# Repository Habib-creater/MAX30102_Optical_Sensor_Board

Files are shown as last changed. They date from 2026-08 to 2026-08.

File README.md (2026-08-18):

# MAX30102 Optical Sensor Board

<p align="center">
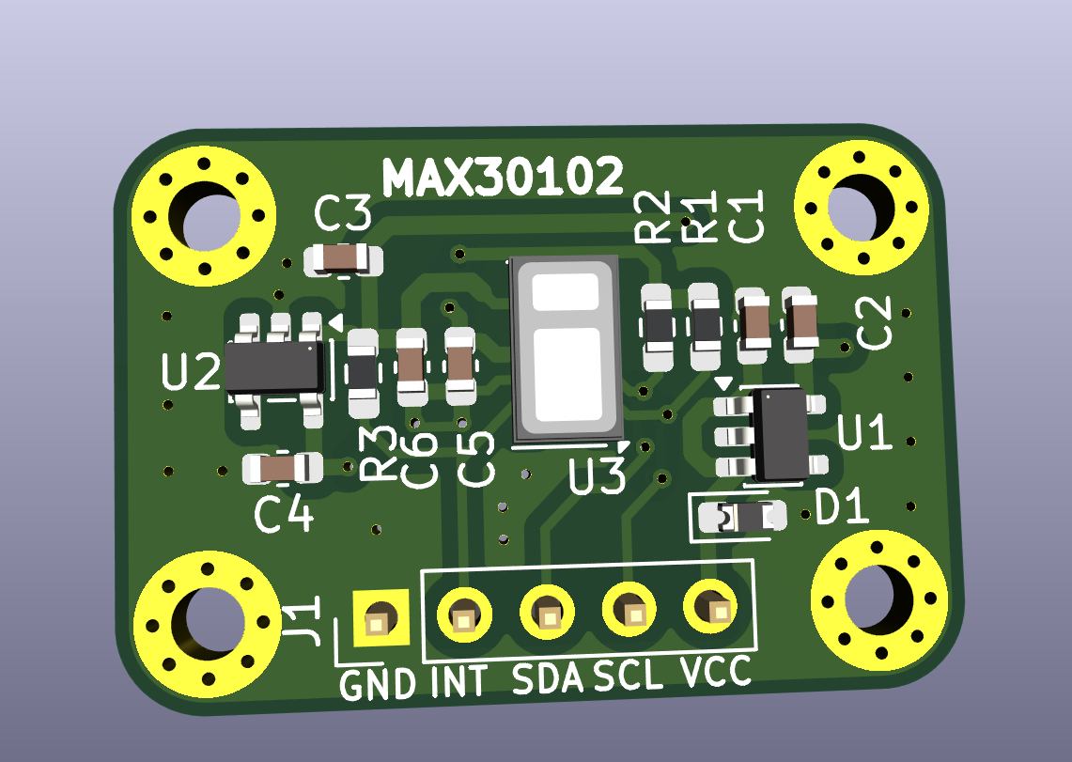
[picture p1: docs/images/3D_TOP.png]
MAX30102 Optical Sensor Board
  
</p>

<p align="center">
  <strong>MAX30102 • Dual Supply Rails • I²C • 2-Layer PCB • KiCad</strong>
</p>

<p align="center">
  A compact optical sensing board centered on the MAX30102
  integrated pulse-oximetry and heart-rate sensor.
</p>

<p align="center">
  <a href="docs/max30102_schematic.pdf">Schematic</a> •
  <a href="bom/MAX30102_BOM.csv">BOM</a> •
  <a href="manufacturing/gerbers/">Gerbers</a> •
  <a href="hardware/kicad/">KiCad Files</a>
</p>

---

## Overview

The **MAX30102 Optical Sensor Board** is a compact 2-layer PCB designed
around the **MAX30102** sensor.

The board provides the MAX30102 with dedicated supply regulation,
I²C connectivity, interrupt access, and a 5-pin external interface.

The complete hardware design package is included in this repository,
covering the native **KiCad project**, schematic, PCB layout, BOM,
Gerber and drill manufacturing files, pick-and-place data, and board
documentation.

---

## Quick Access

| Resource | Description |
|---|---|
| 📐 [Schematic PDF](docs/max30102_schematic.pdf) | Electrical schematic |
| 📦 [Bill of Materials](bom/MAX30102_BOM.csv) | Component BOM |
| 🏭 [Gerber & Drill Files](manufacturing/gerbers/) | PCB manufacturing data |
| 🔧 [KiCad Project](hardware/kicad/) | Native KiCad design files |
| 🖼️ [Board Images](docs/images/) | 3D renders and PCB views |
| 📍 [Pick-and-Place Data](manufacturing/pick-and-place/) | Component placement files |

---

## Key Features

| Feature | Details |
|---|---|
| **Optical Sensor** | MAX30102 |
| **Sensor Function** | Pulse oximetry and heart-rate sensing |
| **Digital Interface** | I²C |
| **Interrupt** | Dedicated INT connection |
| **Input Supply** | +5 V |
| **Logic / Sensor Rail** | +3.3 V |
| **LED Supply Rail** | +1.8 V |
| **3.3 V Regulator** | AP2112K-3.3 |
| **1.8 V Regulator** | TLV70018 |
| **Protection** | SMAJ5.0A TVS diode |
| **External Interface** | 1×5 pin header |
| **PCB** | 2-layer |
| **EDA Software** | KiCad |
| **PCB Thickness** | 1.6 mm |
| **Manufacturing Data** | Gerber + PTH/NPTH drill |
| **Assembly Data** | Pick-and-place CSV |

---

## PCB Preview

### 3D Board Render

<p align="center">
  MAX30102 Board Top 3D Render
</p>

### PCB Front Layout

<p align="center">
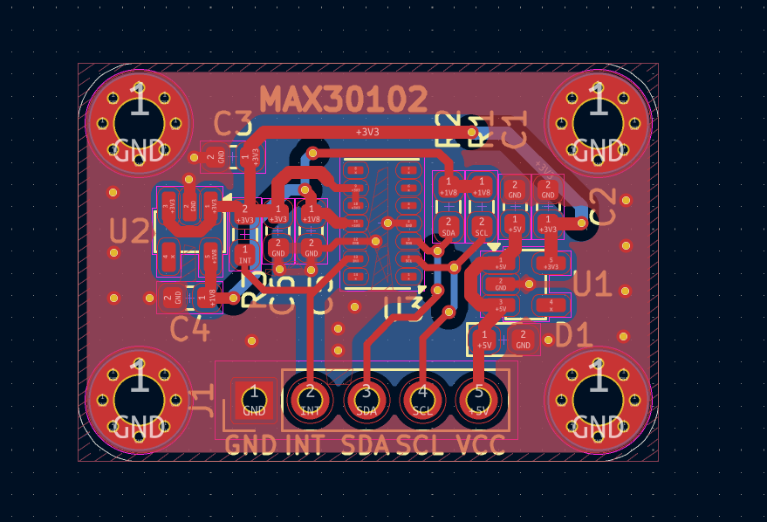
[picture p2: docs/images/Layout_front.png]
MAX30102 PCB Front Layout
  
</p>

### PCB Back Layout

<p align="center">
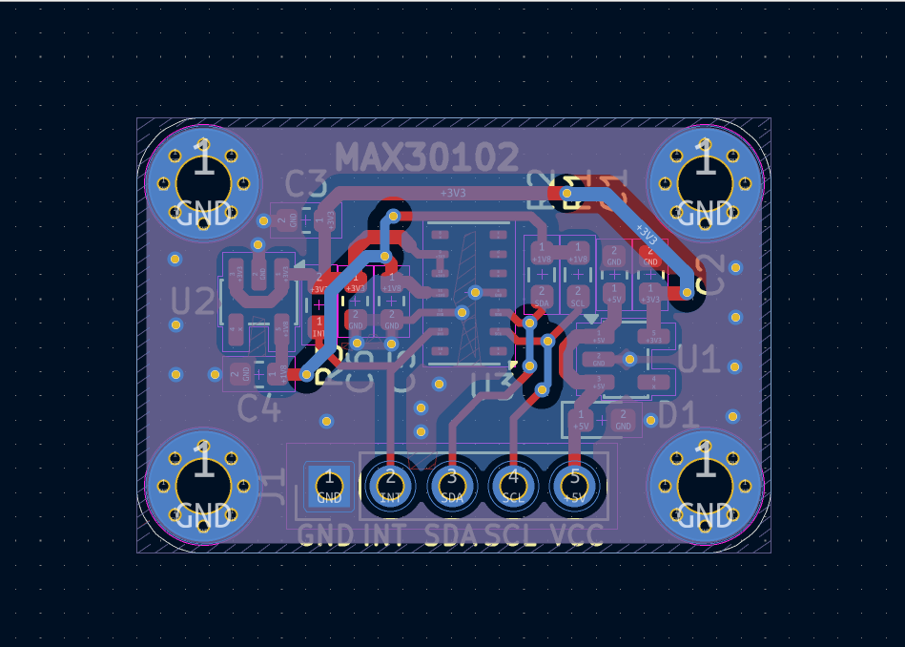
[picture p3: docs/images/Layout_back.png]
MAX30102 PCB Back Layout
  
</p>

### 3D Bottom View

<p align="center">
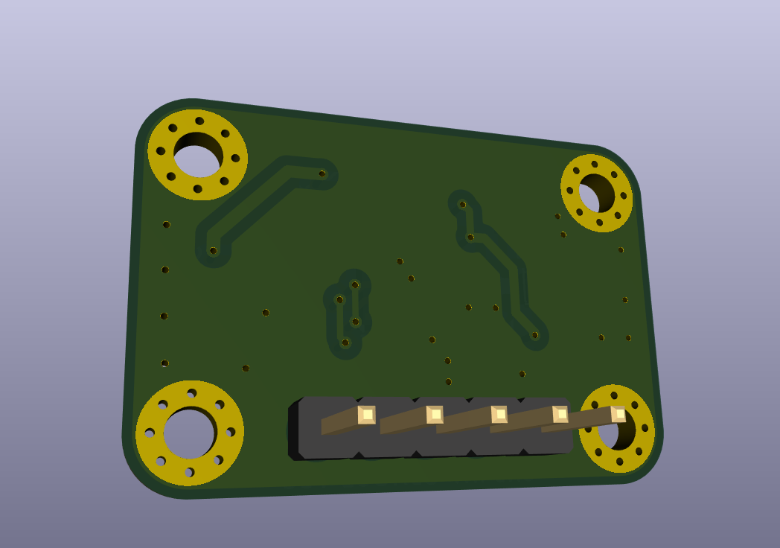
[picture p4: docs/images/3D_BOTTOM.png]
MAX30102 Board Bottom 3D Render
  
</p>

---

## Hardware Architecture

The board is organized around the MAX30102 sensor and its associated
power and interface circuitry.

### MAX30102 Sensor

The **MAX30102** integrates optical sensing functionality for
pulse-oximetry and heart-rate applications.

The sensor interface exposes:

- I²C clock — SCL
- I²C data — SDA
- Interrupt — INT
- Sensor supply — +1.8 V
- LED supply — +3.3V V

### Power Architecture

The board contains dedicated regulation stages for the sensor system:

- **+5 V input**
- **AP2112K-3.3** for the +3.3 V rail
- **TLV70018** for the +1.8 V rail
- Input transient protection

### External Interface

A 5-pin header provides the primary external connection to the board.

| Pin | Signal |
|---|---|
| 1 | +3.3 V |
| 2 | GND |
| 3 | +5 V |
| 4 | SCL |
| 5 | SDA |

The interrupt signal is routed to the MAX30102 interface circuitry.

---

## PCB Design

The board is implemented as a **2-layer PCB** using **KiCad**.

### PCB Characteristics

- 2-layer signal routing
- 1.6 mm board thickness
- Compact sensor-oriented layout
- Dedicated regulated supply rails
- I²C interface routing
- MAX30102 sensor placement
- Input transient protection
- External 5-pin interface

---

## Design Files

The native KiCad project is located in:

[**hardware/kicad/**](hardware/kicad/)

### Main Files

| File | Description |
|---|---|
| `max30102_pcb.kicad_pro` | KiCad project |
| `max30102_pcb.kicad_sch` | Schematic source |
| `max30102_pcb.kicad_pcb` | PCB layout |

The exported schematic PDF is available in
[**docs/**](docs/).

---

## Manufacturing Outputs

The manufacturing package is available in:

[**manufacturing/gerbers/**](manufacturing/gerbers/)

The package contains:

- Front copper
- Back copper
- Front solder paste
- Back solder paste
- Front silkscreen
- Back silkscreen
- Front solder mask
- Back solder mask
- Board outline
- PTH drill data
- NPTH drill data
- Gerber job file

---

## Bill of Materials

The component BOM is available in:

[**bom/MAX30102_BOM.csv**](bom/MAX30102_BOM.csv)

The BOM contains the component references, quantities, values,
footprints, and available manufacturer/supplier information associated
with the design.

---

## Pick-and-Place Data

Assembly placement data is available in:

[**manufacturing/pick-and-place/**](manufacturing/pick-and-place/)

The package contains separate top-side and bottom-side component
position CSV files.

---

## Documentation

The repository includes:

- Electrical schematic PDF
- PCB front layout
- PCB back layout
- 3D top render
- 3D bottom render
- Bill of materials
- Manufacturing outputs
- Pick-and-place data
- Native KiCad design files

---

## Project Status

| Item | Status |
|---|---|
| Schematic | ✅ Completed |
| PCB Layout | ✅ Completed |
| PCB Layer Count | ✅ 2-layer |
| KiCad Project | ✅ Included |
| BOM | ✅ Included |
| Gerber Files | ✅ Generated |
| Drill Files | ✅ Generated |
| Pick-and-Place Data | ✅ Included |
| Documentation | ✅ Included |

---

## Repository Structure

```text
.
├── hardware/
│   └── kicad/
│       ├── max30102_pcb.kicad_pro
│       ├── max30102_pcb.kicad_sch
│       └── max30102_pcb.kicad_pcb
│
├── manufacturing/
│   ├── gerbers/
│   │   ├── max30102_pcb-F_Cu.gbr
│   │   ├── max30102_pcb-B_Cu.gbr
│   │   ├── max30102_pcb-F_Silkscreen.gbr
│   │   ├── max30102_pcb-B_Silkscreen.gbr
│   │   ├── max30102_pcb-F_Mask.gbr
│   │   ├── max30102_pcb-B_Mask.gbr
│   │   ├── max30102_pcb-F_Paste.gbr
│   │   ├── max30102_pcb-B_Paste.gbr
│   │   ├── max30102_pcb-Edge_Cuts.gbr
│   │   ├── max30102_pcb-PTH.drl
│   │   ├── max30102_pcb-NPTH.drl
│   │   └── max30102_pcb-job.gbrjob
│   │
│   └── pick-and-place/
│       ├── max30102_pcb-top-pos.csv
│       └── max30102_pcb-bottom-pos.csv
│
├── bom/
│   └── MAX30102_BOM.csv
│
├── docs/
│   ├── images/
│   │   ├── 3D_TOP.png
│   │   ├── 3D_BOTTOM.png
│   │   ├── Layout_front.png
│   │   └── Layout_back.png
│   │
│   └── max30102_schematic.pdf
│
├── .gitignore
├── CONTRIBUTING.md
├── LICENSE
└── README.md
```

---

## License

The hardware design files in this repository are licensed under the
**CERN Open Hardware Licence Version 2 - Strongly Reciprocal
(CERN-OHL-S-2.0)**.

The licence permits use, modification, distribution, and manufacture
under the terms of the CERN-OHL-S-2.0 licence, with the corresponding
source-sharing requirements for covered hardware.

**Copyright © 2026 Habib Ur Rehman**

See [`LICENSE`](LICENSE) for the licence identifier and official
licence reference.

---

## Author

### Habib Ur Rehman

**Electronics Engineering**  
**University of Engineering and Technology Peshawar (Abbottabad Campus)**

### Connect

- **GitHub:** [Habib-creater](https://github.com/Habib-creater)
- **LinkedIn:** [Habib Ur Rehman](https://www.linkedin.com/in/habib-ur-rehman-8321182b4/)

---

<p align="center">
  <strong>MAX30102 Optical Sensor Board</strong><br>
  Compact Open Hardware Sensor Platform
</p>

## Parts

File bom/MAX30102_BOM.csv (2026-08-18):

Reference | Qty | Value | DNP | Exclude from BOM | Footprint | Manufacturer | Manufacturer part no | Supplier | Supplier Part no | supplier link
C1,C2 | 2 | 10u |  |  | Capacitor_SMD:C_0603_1608Metric | Samsung Electro-Mechanics | CL10X106MO8NRWC | DigiKey | 1276-CL10X106MO8NRWCCT-ND | https://www.digikey.com/en/products/detail/samsung-electro-mechanics/CL10X106MO8NRWC/27519542
C3 | 1 | 1u |  |  | Capacitor_SMD:C_0603_1608Metric | TDK | CGA3E1X7R1C105K080DC | DigiKey | 445-CGA3E1X7R1C105K080DCCT-ND | https://www.digikey.com/en/products/detail/tdk/CGA3E1X7R1C105K080DC/22106147
C4 | 1 | 2.2u |  |  | Capacitor_SMD:C_0603_1608Metric | Samsung Electro-Mechanics | CL10B225KP8NFNC | DigiKey | 1276-2016-1-ND | https://www.digikey.com/en/products/detail/samsung-electro-mechanics/CL10B225KP8NFNC/3887674
C5,C6 | 2 | 0.1u |  |  | Capacitor_SMD:C_0603_1608Metric | Samsung Electro-Mechanics | CL10B104KO8NNNC | DigiKey | 1276-1005-1-ND | https://www.digikey.com/en/products/detail/samsung-electro-mechanics/CL10B104KO8NNNC/3886663
D1 | 1 | SMAJ5.0A |  |  | Diode_SMD:D_0603_1608Metric_Pad1.05x0.95mm_HandSolder | KYOCERA AVX | GG0603052R542P | DigiKey | 478-GG0603052R542PCT-ND | https://www.digikey.com/en/products/detail/kyocera-avx/GG0603052R542P/14552136
H1,H2,H3,H4 | 4 | MountingHole_Pad |  | Excluded from BOM | MountingHole:MountingHole_2.2mm_M2_Pad_Via
J1 | 1 | Conn_01x05_Pin |  |  | Connector_PinHeader_2.54mm:PinHeader_1x05_P2.54mm_Vertical | Samtec Inc. | TS-105-G-A | DigiKey | 612-TS-105-G-A-ND | https://www.digikey.com/en/products/detail/samtec-inc/TS-105-G-A/1105457
R1,R2,R3 | 3 | 4.7K |  |  | Resistor_SMD:R_0603_1608Metric_Pad0.98x0.95mm_HandSolder | YAGEO | RC0603FR-074K7L | DigiKey | 311-4.70KHRCT-ND | https://www.digikey.com/en/products/detail/yageo/RC0603FR-074K7L/727212
U1 | 1 | AP2112K-3.3 |  |  | Package_TO_SOT_SMD:SOT-23-5 | Diodes Incorporated | AP2112K-3.3TRG1 | DigiKey | AP2112K-3.3TRG1DICT-ND | https://www.digikey.com/en/products/detail/diodes-incorporated/AP2112K-3-3TRG1/4470746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
U2 | 1 | TLV70018_SOT23-5 |  |  | Package_TO_SOT_SMD:SOT-23-5 | Texas Instruments | TLV70018DDCR | DigiKey | 296-32410-1-ND | https://www.digikey.com/en/products/detail/texas-instruments/TLV70018DDCR/2232568
U3 | 1 | MAX30102 |  |  | OptoDevice:Maxim_OLGA-14_3.3x5.6mm_P0.8mm | Analog Devices Inc./Maxim Integrated | MAX30102EFD+T | DigiKey | MAX30102EFD+TCT-ND | https://www.digikey.com/en/products/detail/analog-devices-inc-maxim-integrated/MAX30102EFD-T/6188734

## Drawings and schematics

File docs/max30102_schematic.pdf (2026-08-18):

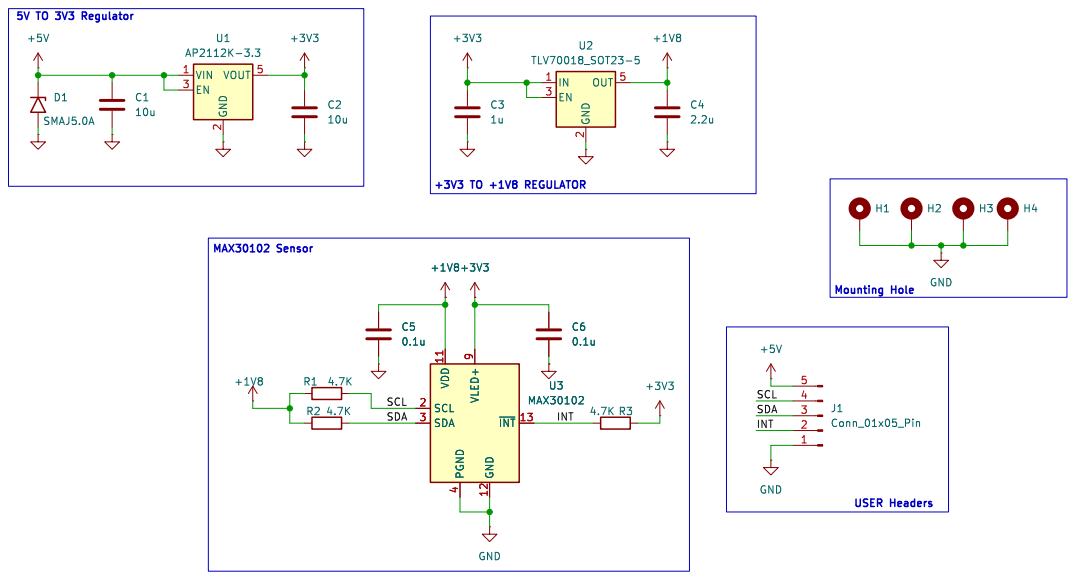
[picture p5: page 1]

2 OUT 5 U2 TLV70018_SOT23-5 VIN 1 EN 3 GND

Id: 1/1 Title: File: max30102_pcb.kicad_sch Sheet: /

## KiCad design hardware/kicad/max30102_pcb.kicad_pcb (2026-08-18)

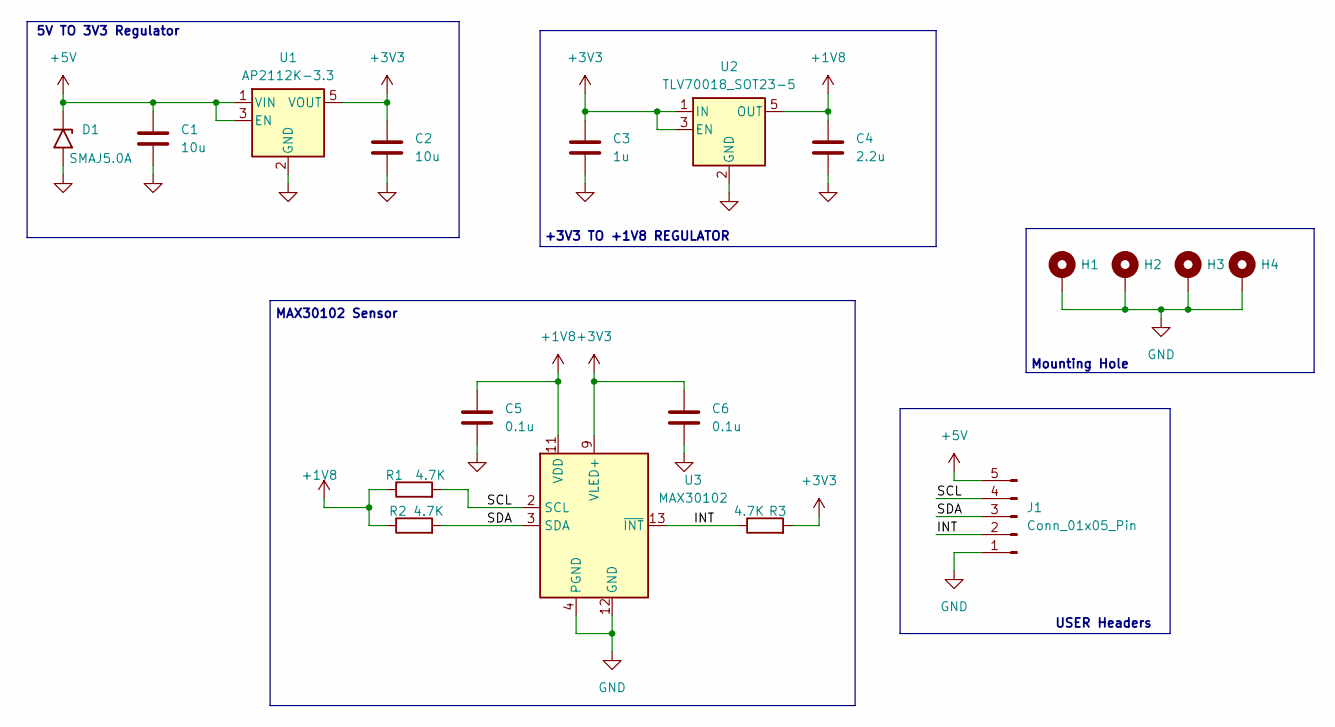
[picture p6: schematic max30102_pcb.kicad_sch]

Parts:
C1, C2: 10u; C_0603_1608Metric
C3: 1u; C_0603_1608Metric
C4: 2.2u; C_0603_1608Metric
C5, C6: 0.1u; C_0603_1608Metric
D1: SMAJ5.0A; D_0603_1608Metric_Pad1.05x0.95mm_HandSolder
H1, H2, H3, H4: MountingHole_Pad; MountingHole_2.2mm_M2_Pad_Via
J1: Conn_01x05_Pin; PinHeader_1x05_P2.54mm_Vertical
R1, R2, R3: 4.7K; R_0603_1608Metric_Pad0.98x0.95mm_HandSolder
U1: AP2112K-3.3; SOT-23-5
U2: TLV70018_SOT23-5; SOT-23-5
U3: MAX30102; Maxim_OLGA-14_3.3x5.6mm_P0.8mm

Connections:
+1V8: C4.1, C5.1, R1.1, R2.1, U2.5 (OUT), U3.11 (VDD)
+3V3: C2.1, C3.1, C6.1, R3.2, U1.5 (VOUT), U2.1 (IN), U2.3 (EN), U3.9 (VLED+), U3.10 (VLED+)
+5V: C1.1, D1.1 (A1), J1.5, U1.1 (VIN), U1.3 (EN)
/INT: J1.2, R3.1, U3.13 (~INT)
/SCL: J1.4, R1.2, U3.2 (SCL)
/SDA: J1.3, R2.2, U3.3 (SDA)
GND: C1.2, C2.2, C3.2, C4.2, C5.2, C6.2, D1.2 (A2), H1.1, H2.1, H3.1, H4.1, J1.1, U1.2 (GND), U2.2 (GND), U3.4 (PGND), U3.12 (GND)

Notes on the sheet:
5V TO 3V3 Regulator
Mounting Hole
MAX30102 Sensor
USER Headers
+3V3 TO +1V8 REGULATOR

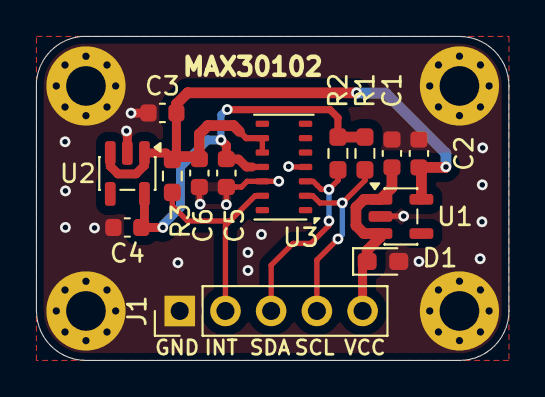
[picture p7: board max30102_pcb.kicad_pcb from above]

Board: 2 copper layers, 26.2 x 18.0 mm, 18 parts (0 on the bottom side), 7 nets.
